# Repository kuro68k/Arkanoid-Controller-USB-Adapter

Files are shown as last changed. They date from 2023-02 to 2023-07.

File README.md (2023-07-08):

# Arkanoid-Controller-USB-Adapter

Adapter for the Famicom Arkanoid controller to USB.

Two modes are available, an absolute position mode that is good for Breakout under MAME, and a mouse emulation mode that is better for Arkanoid under MAME.

You need a decent USB port for this. If there is electrical noise it can cause the position to jump. I use a powered hub.

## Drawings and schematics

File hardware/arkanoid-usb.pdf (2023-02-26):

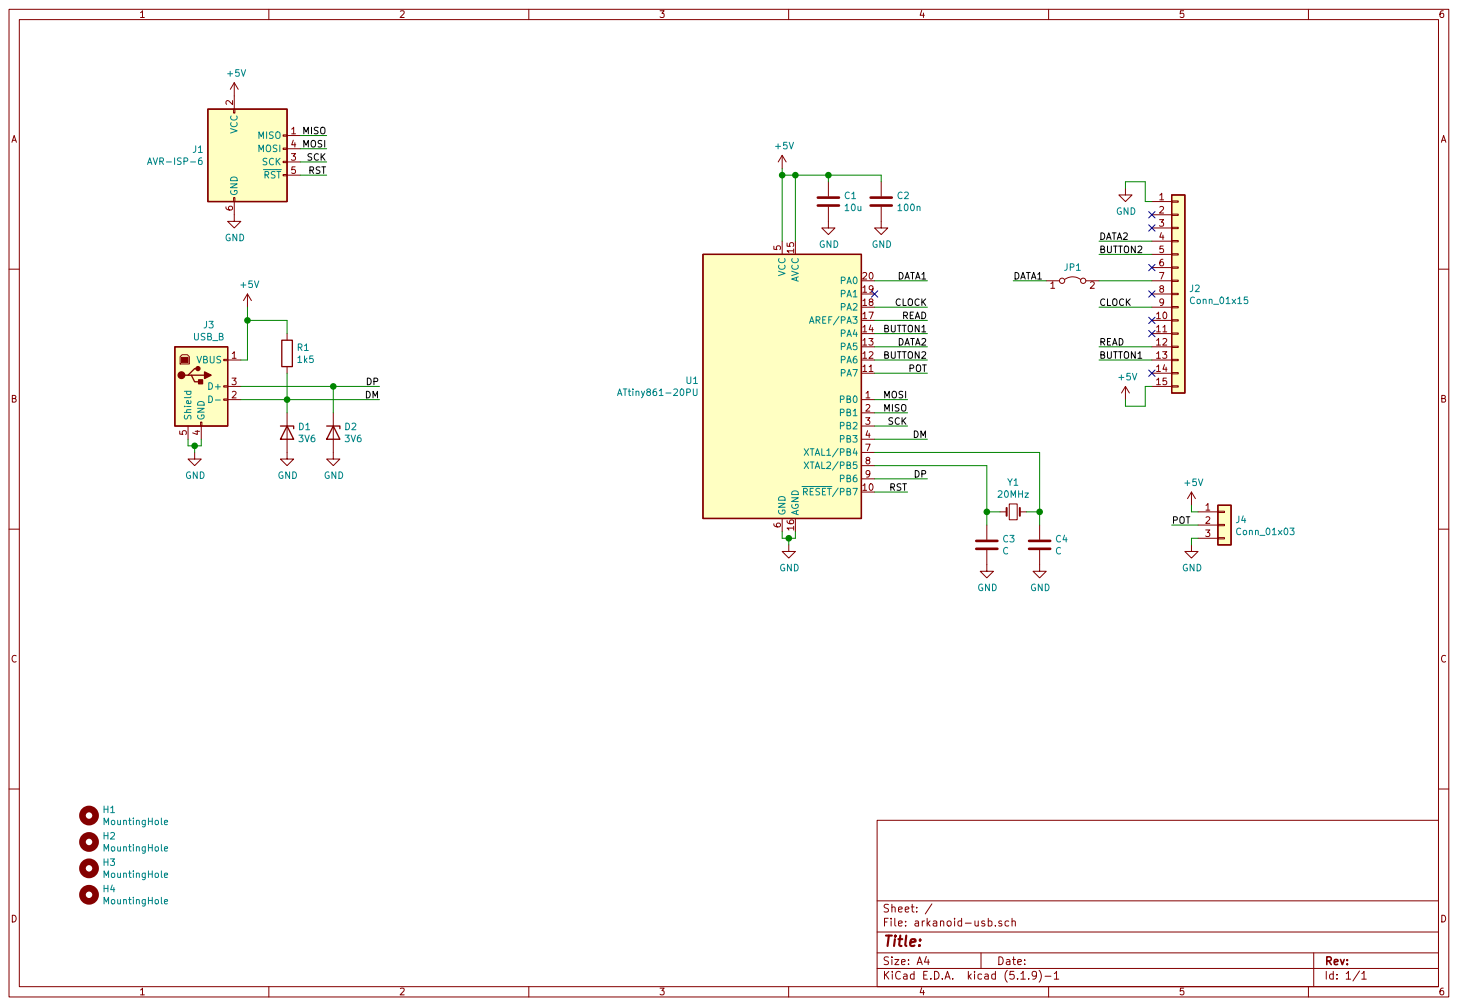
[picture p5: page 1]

2 SCK 3 MOSI 4 RST 5 GND

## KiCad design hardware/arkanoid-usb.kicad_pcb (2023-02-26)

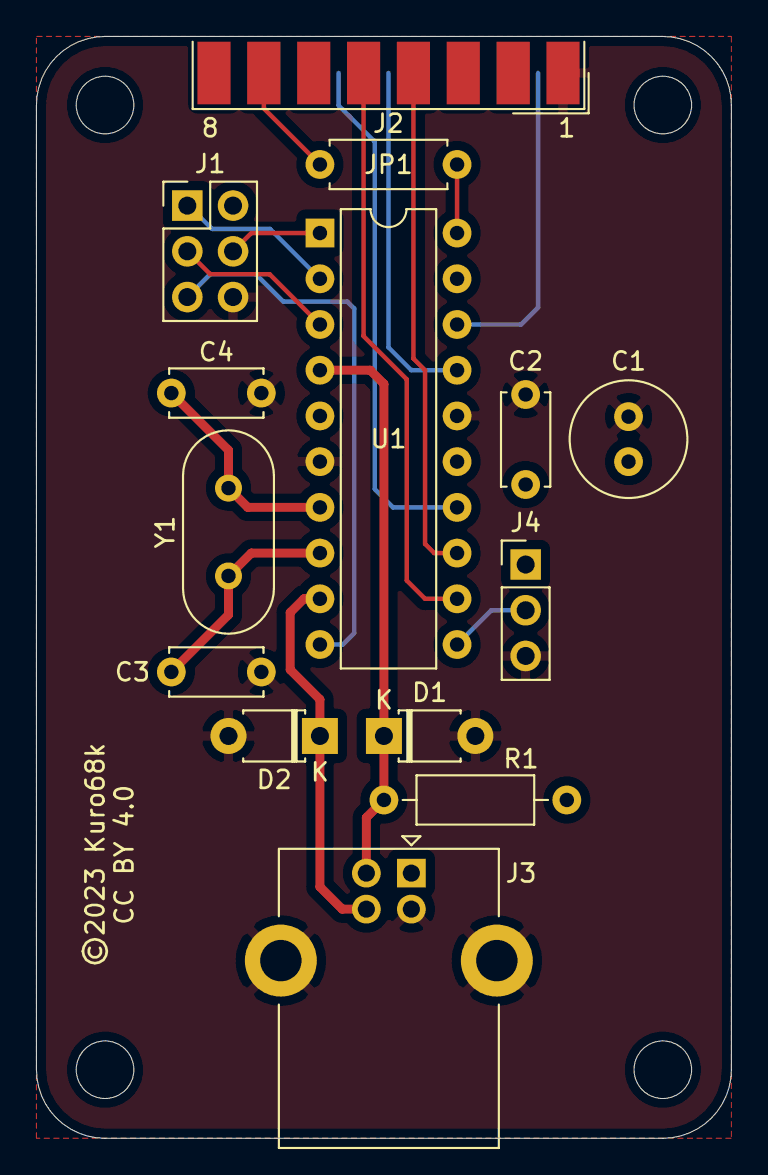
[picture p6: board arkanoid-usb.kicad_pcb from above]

Board: 2 copper layers, 38.6 x 61.2 mm, 18 parts (0 on the bottom side), 18 nets.

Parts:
C1: 10u; C_Radial_D6.3mm_H5.0mm_P2.50mm
C2: 100n; C_Disc_D5.0mm_W2.5mm_P5.00mm
C3, C4: C; C_Disc_D5.0mm_W2.5mm_P5.00mm
D1, D2: 3V6; D_T-1_P5.08mm_Horizontal
H1, H2, H3, H4: MountingHole; MountingHole_3.2mm_M3
J1: AVR-ISP-6; PinHeader_2x03_P2.54mm_Vertical
J2: Conn_01x15; DSUB-15_Male_EdgeMount_P2.77mm
J3: USB_B; USB_B_Lumberg_2411_02_Horizontal
J4: Conn_01x03; PinHeader_1x03_P2.54mm_Vertical
JP1: Jumper_2_Bridged; R_Axial_DIN0207_L6.3mm_D2.5mm_P7.62mm_Horizontal
R1: 1k5; R_Axial_DIN0207_L6.3mm_D2.5mm_P10.16mm_Horizontal
U1: ATtiny861-20PU; DIP-20_W7.62mm
Y1: 20MHz; Crystal_HC49-U_Vertical

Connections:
+5V: C1.1, C2.1, J1.2, J2.15, J3.1, J4.1, R1.1, U1.5, U1.15
/BUTTON1: J2.13, U1.14
/BUTTON2: J2.5, U1.12
/CLOCK: J2.9, U1.18
/DATA1: JP1.1, U1.20
/DATA2: J2.4, U1.13
/DM: D1.1, J3.2, R1.2, U1.4
/DP: D2.1, J3.3, U1.9
/MISO: J1.1, U1.2
/MOSI: J1.4, U1.1
/POT: J4.2, U1.11
/READ: J2.12, U1.17
/RST: J1.5, U1.10
/SCK: J1.3, U1.3
GND: C1.2, C2.2, C3.2, C4.2, D1.2, D2.2, J1.6, J2.1, J3.4, J3.5, J4.3, U1.6, U1.16
unnamed: C3.1, U1.8, Y1.1
unnamed: C4.1, U1.7, Y1.2
unnamed: J2.7, JP1.2

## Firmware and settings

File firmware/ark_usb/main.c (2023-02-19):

/*
 * ark_usb.c
 *
 * Created: 05/02/2023 16:04:18
 * Author : kuro68k
 */ 

#include <stdbool.h>
#include <avr/io.h>
#include <avr/interrupt.h>  /* for sei() */
#include <avr/pgmspace.h>   /* required by usbdrv.h */
#include "usbdrv.h"
#include <util/delay.h>     /* for _delay_ms() */

#define ABSOLUTE_MODE

PROGMEM const char usbHidReportDescriptor[USB_CFG_HID_REPORT_DESCRIPTOR_LENGTH] = { /* USB report descriptor, size must match usbconfig.h */
    0x05, 0x01,                    // USAGE_PAGE (Generic Desktop)
    0x09, 0x04,                    // USAGE (Joystick)
    0xa1, 0x01,                    // COLLECTION (Application)
    0xa1, 0x00,                    //   COLLECTION (Physical)
    0x05, 0x09,                    //     USAGE_PAGE (Button)
    0x19, 0x01,                    //     USAGE_MINIMUM (Button 1)
    0x29, 0x01,                    //     USAGE_MAXIMUM (Button 1)
    0x15, 0x00,                    //     LOGICAL_MINIMUM (0)
    0x25, 0x01,                    //     LOGICAL_MAXIMUM (1)
    0x95, 0x01,                    //     REPORT_COUNT (1)
    0x75, 0x01,                    //     REPORT_SIZE (1)
    0x81, 0x02,                    //     INPUT (Data,Var,Abs)
    0x95, 0x01,                    //     REPORT_COUNT (1)
    0x75, 0x07,                    //     REPORT_SIZE (7)
    0x81, 0x03,                    //     INPUT (Cnst,Var,Abs)
    0x05, 0x01,                    //     USAGE_PAGE (Generic Desktop)
    0x09, 0x30,                    //     USAGE (X)
#ifdef ABSOLUTE_MODE
    0x16, 0x00, 0x00,              //     LOGICAL_MINIMUM (0)
    0x26, 0xff, 0x01,              //     LOGICAL_MAXIMUM (511)
#else
    0x16, 0x01, 0xff,              //     LOGICAL_MINIMUM (-255)
    0x26, 0xff, 0x00,              //     LOGICAL_MAXIMUM (255)
#endif
    0x75, 0x09,                    //     REPORT_SIZE (9)
    0x95, 0x01,                    //     REPORT_COUNT (1)
    0x81, 0x02,                    //     INPUT (Data,Var,Abs)
    0x75, 0x07,                    //     REPORT_SIZE (7)
    0x95, 0x01,                    //     REPORT_COUNT (1)
    0x81, 0x03,                    //     INPUT (Cnst,Var,Abs)
    0xc0,                          //     END_COLLECTION
    0xc0                           // END_COLLECTION
};

typedef struct{
	uint8_t	button;
	int16_t	pot;
}report_t;

static report_t reportBuffer;
static volatile uint8_t reportBufferIdx_AT = 0;
static uchar    idleRate;   /* repeat rate for keyboards, never used for mice */

// PORT A
#define	DATA1_PIN_bm	(1<<0)
#define	CLOCK_PIN_bm	(1<<2)
#define	READ_PIN_bm		(1<<3)
#define	BUTTON1_PIN_bm	(1<<4)
#define	DATA2_PIN_bm	(1<<5)
#define	BUTTON2_PIN_bm	(1<<6)
#define	POT_PIN_bm		(1<<7)


int main(void)
{
	PORTA = DATA1_PIN_bm | BUTTON1_PIN_bm | DATA2_PIN_bm | BUTTON2_PIN_bm;	// pull ups
	DDRA =	CLOCK_PIN_bm | READ_PIN_bm;

	PORTB = 0b10000111;		// programmer SPI interface pull ups
	DDRB =  0b00000001;		// MOSI as output

	// USB interrupt, port B pin 6 change, INT0
	MCUCR |= (1<<ISC00);	// any change triggers the interrupt
	MCUCR &= ~(1<<ISC01);
	GIMSK = (1<<INT0);

	// USI in SPI mode on PORT B
	USIPP = (1<<USIPOS);	// PORT A
	USICR = (1<<USIWM0);	// 3 wire mode

	usbInit();
	usbDeviceDisconnect();  // enforce re-enumeration, do this while interrupts are disabled!
	_delay_ms(255);			// USB reset
	usbDeviceConnect();
	sei();

#ifdef ABSOLUTE_MODE
	uint16_t min = 255;
	uint16_t max = 256;
#else
	uint16_t last_pot = 511;
#endif
	for (;;)
	{
		usbPoll();
		if (usbInterruptIsReady())
		{
			// clock out bits via SPI
			USISR = (1<<USIOIF);		// clear overflow flag, counter = 0
			for (uint8_t i = 0; i < 8; i++)
			{
				_delay_us(10);
				USICR = (1<<USIWM0) | (1<<USICS1) | (1<<USITC);
				_delay_us(10);
				USICR = (1<<USIWM0) | (1<<USICS1) | (1<<USICLK) | (1<<USITC);
			}
			int16_t pot = (uint16_t)USIDR << 1;
			_delay_us(10);
			USICR = (1<<USIWM0) | (1<<USICS1) | (1<<USITC);
			_delay_us(10);
			USICR = (1<<USIWM0) | (1<<USICS1) | (1<<USICLK) | (1<<USITC);
			pot |= USIDR & 1;
			if (pot > 511)
				pot = 511;

			if ((pot > 100) && (pot < 500))
			{
#ifdef ABSOLUTE_MODE
				if (min > pot)
					min = pot;
				if (max < pot)
					max = pot;
				float scale = 511 / ((float)max - (float)min);
				scale *= (float)pot - (float)min;
				pot = scale;
				if (pot > 511)
					pot = 511;
#else
				int16_t temp = pot;
				pot = pot - last_pot;
				last_pot = temp;
				pot *= 10;
#endif
				cli();
				reportBuffer.pot = pot;
				reportBuffer.button = PINA & BUTTON1_PIN_bm ? 0 : 1;
				sei();

				usbSetInterrupt((uchar *)&reportBuffer, sizeof(report_t));
			}

			// read controller again
			PORTA |= READ_PIN_bm;
			_delay_us(100);
			PORTA &= ~READ_PIN_bm;
		}
	}
}

usbMsgLen_t usbFunctionSetup(uchar data[8])
{
	usbRequest_t    *rq = (void *)data;

	/* The following requests are never used. But since they are required by
	* the specification, we implement them in this example.
	*/
	if((rq->bmRequestType & USBRQ_TYPE_MASK) == USBRQ_TYPE_CLASS)	/* class request type */
	{
		if(rq->bRequest == USBRQ_HID_GET_REPORT)	/* wValue: ReportType (highbyte), ReportID (lowbyte) */
		{
			/* we only have one report type, so don't look at wValue */
			usbMsgPtr = (usbMsgPtr_t)&reportBuffer;
			return sizeof(report_t);
		}
		else if(rq->bRequest == USBRQ_HID_GET_IDLE)
		{
			usbMsgPtr = (usbMsgPtr_t)&idleRate;
			return 1;
		}
		else if(rq->bRequest == USBRQ_HID_SET_IDLE)
		{
			idleRate = rq->wValue.bytes[1];
		}
	}
	else
	{
		/* no vendor specific requests implemented */
	}
	return 0;   /* default for not implemented requests: return no data back to host */
}

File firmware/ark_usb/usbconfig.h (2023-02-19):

/* Name: usbconfig.h
 * Project: V-USB, virtual USB port for Atmel's(r) AVR(r) microcontrollers
 * Author: Christian Starkjohann
 * Creation Date: 2005-04-01
 * Tabsize: 4
 * Copyright: (c) 2005 by OBJECTIVE DEVELOPMENT Software GmbH
 * License: GNU GPL v2 (see License.txt), GNU GPL v3 or proprietary (CommercialLicense.txt)
 */

#ifndef __usbconfig_h_included__
#define __usbconfig_h_included__

#ifndef F_CPU
	#define F_CPU 20000000UL
#endif

/*
General Description:
This file is an example configuration (with inline documentation) for the USB
driver. It configures V-USB for USB D+ connected to Port D bit 2 (which is
also hardware interrupt 0 on many devices) and USB D- to Port D bit 4. You may
wire the lines to any other port, as long as D+ is also wired to INT0 (or any
other hardware interrupt, as long as it is the highest level interrupt, see
section at the end of this file).
+ To create your own usbconfig.h file, copy this file to your project's
+ firmware source directory) and rename it to "usbconfig.h".
+ Then edit it accordingly.
*/

/* ---------------------------- Hardware Config ---------------------------- */

#define USB_CFG_IOPORTNAME      B
/* This is the port where the USB bus is connected. When you configure it to
 * "B", the registers PORTB, PINB and DDRB will be used.
 */
#define USB_CFG_DMINUS_BIT      3
/* This is the bit number in USB_CFG_IOPORT where the USB D- line is connected.
 * This may be any bit in the port.
 */
#define USB_CFG_DPLUS_BIT       6
/* This is the bit number in USB_CFG_IOPORT where the USB D+ line is connected.
 * This may be any bit in the port. Please note that D+ must also be connected
 * to interrupt pin INT0! [You can also use other interrupts, see section
 * "Optional MCU Description" below, or you can connect D- to the interrupt, as
 * it is required if you use the USB_COUNT_SOF feature. If you use D- for the
 * interrupt, the USB interrupt will also be triggered at Start-Of-Frame
 * markers every millisecond.]
 */
#define USB_CFG_CLOCK_KHZ       (F_CPU/1000)
/* Clock rate of the AVR in kHz. Legal values are 12000, 12800, 15000, 16000,
 * 16500, 18000 and 20000. The 12.8 MHz and 16.5 MHz versions of the code
 * require no crystal, they tolerate +/- 1% deviation from the nominal
 * frequency. All other rates require a precision of 2000 ppm and thus a
 * crystal!
 * Since F_CPU should be defined to your actual clock rate anyway, you should
 * not need to modify this setting.
 */
#define USB_CFG_CHECK_CRC       0
/* Define this to 1 if you want that the driver checks integrity of incoming
 * data packets (CRC checks). CRC checks cost quite a bit of code size and are
 * currently only available for 18 MHz crystal clock. You must choose
 * USB_CFG_CLOCK_KHZ = 18000 if you enable this option.
 */

/* ----------------------- Optional Hardware Config ------------------------ */

/* #define USB_CFG_PULLUP_IOPORTNAME   D */
/* If you connect the 1.5k pullup resistor from D- to a port pin instead of
 * V+, you can connect and disconnect the device from firmware by calling
 * the macros usbDeviceConnect() and usbDeviceDisconnect() (see usbdrv.h).
 * This constant defines the port on which the pullup resistor is connected.
 */
/* #define USB_CFG_PULLUP_BIT          4 */
/* This constant defines the bit number in USB_CFG_PULLUP_IOPORT (defined
 * above) where the 1.5k pullup resistor is connected. See description
 * above for details.
 */

/* --------------------------- Functional Range ---------------------------- */
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

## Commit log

2023-02-05 Initial code
    [tiny45-rc.sch, with-series-diodes.sch, with-vreg.sch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]
2023-02-19 Auto calibration
2023-02-26 Corrected programming header
    [arkanoid-usb.kicad_pcb, arkanoid-usb.sch]

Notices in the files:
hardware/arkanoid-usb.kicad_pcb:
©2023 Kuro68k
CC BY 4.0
